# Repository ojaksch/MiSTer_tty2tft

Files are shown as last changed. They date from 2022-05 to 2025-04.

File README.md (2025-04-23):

# This project is now archived and unmaintained

---

*A display add-on for the **[MiSTer FPGA]***

<br>


<div align = right>
<div align = center>

This project is the big brother of Venice's famous [tty2oled](https://github.com/venice1200/MiSTer_tty2oled/), <br>
based on an ESP32 in Arduino MEGA format and an <br>
appropriate 8-bit-bus **TFT** display as a shield. <br>
This setup plays JPG pictures and MJPEG videos <br>
from SD card, optional downloading via WiFi.

Head over to the [documentation folder how to set it up.](https://github.com/ojaksch/MiSTer_tty2tft/tree/main/doc)
</div>
</div>

---

### License

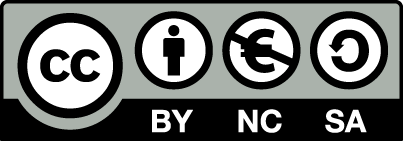
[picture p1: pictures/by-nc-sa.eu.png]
CC BY-NC-SA 4.0
  
[Attribution-NonCommercial-ShareAlike 4.0 International (CC BY-NC-SA 4.0)](https://creativecommons.org/licenses/by-nc-sa/4.0/)

<!----------------------------------------------------------------------------->

[MiSTer FPGA]: https://github.com/MiSTer-devel

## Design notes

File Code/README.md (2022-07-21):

### Used libraries:

- [JPEGDEC](https://github.com/bitbank2/JPEGDEC/)
- [GFX_Library_for_Arduino](https://github.com/moononournation/Arduino_GFX)
- [ESP32Time](https://github.com/fbiego/ESP32Time)
- [CronAlarms](https://github.com/Martin-Laclaustra/CronAlarms)
- [U8g2](https://github.com/olikraus/u8g2)
- [ftpsrv](https://github.com/schreibfaul1/ESP32FTPServer)
- [JpegFunc.h and MjpegClass.h (modified by me)](https://github.com/moononournation/RGB565_video)

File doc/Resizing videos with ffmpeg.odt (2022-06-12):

# Resizing videos with ffmpeg (https://superuser.com/questions/547296/resizing-videos-with-ffmpeg-avconv-to-fit-into-static-sized-player)

(Source: https://superuser.com/questions/547296/resizing-videos-with-ffmpeg-avconv-to-fit-into-static-sized-player/1136305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)

A simple method is to use the force_original_aspect_ratio option in the scale filter (https://ffmpeg.org/ffmpeg-filters.html#scale).

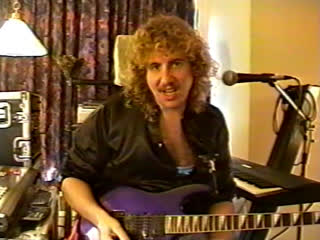
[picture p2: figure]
original image

(https://i.stack.imgur.com/vjgYm.jpg)
Original image. Represents a 640x480, 4:3 aspect ratio video.

In these examples the original image will be scaled to fit into a 1280x720, 16:9 aspect ratio output while preserving the original aspect ratio. To do this you can either:

- Add black bars (or any other color) with pad filter (https://ffmpeg.org/ffmpeg-filters.html#pad) to pillarbox (https://en.wikipedia.org/wiki/Pillarbox) or letterbox (https://en.wikipedia.org/wiki/Letterboxing_(filming)) the image to fit properly, or
- Use the crop filter (https://ffmpeg.org/ffmpeg-filters.html#crop) to cut off the excess

# Pillarbox or letterbox to fit

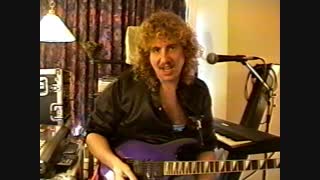
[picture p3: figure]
pillarboxed image

(https://i.stack.imgur.com/wlTki.jpg)
Pillarboxed image. Fitting a 640x480 (4:3) input into a 1280x720 (16:9) output.

ffmpeg -i input -vf "scale=1280:720:force_original_aspect_ratio=decrease,pad=1280:720:-1:-1:color=black" output

- This will upscale the image. If you want to avoid upscaling see the example below.
- Letterboxing will occur instead of pillarboxing if the input aspect ratio is wider than the output aspect ratio. For example, an input with a 2.35:1 aspect ratio fit into a 16:9 output will result in letterboxing.

## Same as above but without upscaling

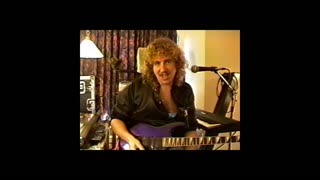
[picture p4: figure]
no upscaling

(https://i.stack.imgur.com/WON8H.jpg)
640x480 (4:3) input into 1280x720 (16:9) output without upscaling.

ffmpeg -i input -vf "scale='min(1280,iw)':min'(720,ih)':force_original_aspect_ratio=decrease,pad=1280:720:-1:-1:color=black" output

# Crop to fit

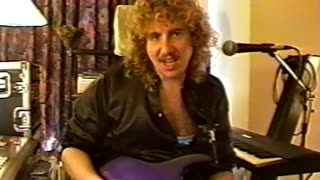
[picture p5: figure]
enter image description here

(https://i.stack.imgur.com/FW2U2.jpg)
Cropped image. 4:3 input aspect ratio, 16:9 output aspect ratio.

Using the crop filter (https://ffmpeg.org/ffmpeg-filters.html#crop) to cut off the excess:

ffmpeg -i input -vf "scale=1280:720:force_original_aspect_ratio=increase,crop=1280:720" output

## Using input images that each vary in size

If you are inputting a series of images, and the images vary in size, add the eval=frame option in the scale filter (https://ffmpeg.org/ffmpeg-filters.html#scale), such as:

ffmpeg -i input -vf "scale=1280:720:force_original_aspect_ratio=decrease:eval=frame,pad=1280:720:-1:-1:color=black" output

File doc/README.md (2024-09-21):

Ready to rumble?

Table of Contents  
[Hardware](#hardware)  
[Software](#software)  
[Media](#media)  
[MJPEG](#mjpeg)  
[The INI files](#the-ini-files)  
[The screensaver](#the-screensaver)  
[Touch function](#touch-function)  
[Swiping](#touch-swipe)  
[Commands](#commands)  
[Color definitions](#color-definitions-used-by-the-display-driver)  
[Initial Animation](initial_animation)  
[Bugs and things to do](#bugs-and-things-still-to-do)  
[Compiling](#compiling)  
[License](#license)  
[Licensees](#licensees)  

---

# Hardware

You need an [ESP32 D1 R32 and an ILI9341 (320x200) 8-bit bus display](https://github.com/ojaksch/MiSTer_tty2tft/blob/main/pictures/d1r32-ili9341.jpg). 
Other 8-bit bus displays should also work (according to librarys documentation). Alternatively you can use the [Adafruit 2.8 SPI based shields](https://www.adafruit.com/product/1947).

- 2024-09: ILI9341-CYD ("Cheap Yellow Display")
- 2022-09: ILI9341 (SPI) (320x240) succesfully tested by Ahmadexp
- 2022-06: ILI9488 (parallel) (480x320) succesfully tested by myself
- 2022-06: ILI9486 (parallel) (480x320) succesfully tested by Salamantecas
- 2022-06: HX8347D (parallel) (320x200) succesfully tested, many many thanks to Salamantecas!  

The ESP with the **parallel** TFT shield needs a [small modifictaion consisting of three cables](https://github.com/ojaksch/MiSTer_tty2tft/blob/main/pictures/d1r32-mod.jpg).
([Source](https://github.com/Bodmer/TFT_eSPI#8-bit-parallel-support)) Not necessary for the SPI shields. 

In order to get the [Adafruit 2.8 SPI based shields](https://www.adafruit.com/product/1947) work on the Wemos D1 R32, it is necessary to [solder the jumper points (D13/12/D13)](https://github.com/ojaksch/MiSTer_tty2tft/blob/main/pictures/ADA28SPI-mod_photo.jpg) on the back of the TFT shield. This is mainly because the Wemos D1 R32 lacks the 6-pin SPI connector.

**Notices:**
- It turned out that a 480x320 display looks great with pictures, but is somewhat too "slow" to play MJPEG videos really fluently. This is stated by the facts 
that MJPEG isn't a videostream...it's a series of single jpg's in one file that are played one after the other and are always shown at 25fps. Keep in mind that a 
480x320 display has a 2.5x resolution of a 320x200 one, so it also has to transfer 2.5 times of data - all this through very limited SD access times.
As a result, my personal recommendation is a 320x200 for pictures **and** videos - or a 480x320 for pictures (and videos if a bit stuttering is acceptable).

- Keep in mind that the ESP32 is using WiFi@2.4 GHz only (if enabled).

That's all!

---

# Software

Follow the instructions below. Don't continue with the next step if something won't run, is showing errors or doing something unexpected/weired.
Call for help first.

- Copy the **content** of *SD_card_content* to a reliable FAT32 formatted SD card <32GB. While beeing there you can fill up the subdirectorys with your own content.
The file **wifi.txt** file contains some important settings only needed if you want to use WiFi, otherwise leave it as it is. When editing, use an editor capable of Linux linebreaks, like notepad++ (Windows).:
  - 1st line: WiFi SSID
  - 2nd line: WiFi Password
  - 3rd line: URL of a picture server for online picture access (set to 127.0.0.1 = disabled)
  - 4th line: WiFi timeout
  - 5th line: WiFi country code
  - 6th line: Opening screen (ORG for my version, OWN for *your* design, OWN0 for *your* design w/o any text overlay
  - 7th line: Display orientation (1 is normal, 3 rotated by 180°)
  - 8th line: Divisor for screen's X-resolution/axis to swipe
  - 9th line: Divisor for screen's Y-resolution/axis to swipe

- Open a ssh-shell to your MiSTer or open a console at MiSTer and logon.

- We will do a quick first test to see that everythins is working / to ensure ESP32 and display are working together. Type in the following line:
for ILI9341: `wget https://raw.githubusercontent.com/ojaksch/tty2tft/main/installer.sh -O - | bash -s -- TEST-ILI9341`  
for ILI9486: `wget https://raw.githubusercontent.com/ojaksch/tty2tft/main/installer.sh -O - | bash -s -- TEST-ILI9486`  
for ILI9488: `wget https://raw.githubusercontent.com/ojaksch/tty2tft/main/installer.sh -O - | bash -s -- TEST-ILI9488`  
for ILI9341SPI: `wget https://raw.githubusercontent.com/ojaksch/tty2tft/main/installer.sh -O - | bash -s -- TEST-ILI9341SPI`  
This will flash a simple and looping graphics demo.   
If you see a message while flashing like
> WARNING: Failed to communicate with the flash chip...

then the ESP doesn't reset quick enough. Just rerun the line from above. 
If flash happened successfuly and demo works, just continue - otherwise stop here, check your hardware/cabling and call for help then.

- Type in  
`wget https://raw.githubusercontent.com/ojaksch/tty2tft/main/installer.sh -O - | bash -s -- FORCE DISPLAYTYPE`  
**DISPLAYTYPE** is the type of your display, one of HX8347D, ILI9341, ILI9486, ILI9488, ILI9341CYD or ILI9341SPI so, for example, your line should read  
`wget https://raw.githubusercontent.com/ojaksch/tty2tft/main/installer.sh -O - | bash -s -- FORCE ILI9341`  
when flashing for a display ILI9341. This will download and flash the ESP firmware. You should see a [welcome screen](https://github.com/ojaksch/MiSTer_tty2tft/blob/main/pictures/000-arcade.jpg) after the reboot of the ESP.  

- Type in  
`wget https://raw.githubusercontent.com/ojaksch/tty2tft/main/update_tty2tft.sh -O - | bash`  
which downloads and setup the software (init and daemon).

Voila, tty2tft is alive :)

---

# Media

JPG pictures must be 320x240 (ILI9341, HX8347D) or 480x320 (ILI9486) pixels in size and should be saved as non-progressive with around 60 percent in compression to achieve 
a good compromise between quality and filesize (=loading time). A filesize around 20kb is fine, the 
smaller, the better, but a filesize around 35kb is ok, too. That's all.

Same goes for the MJPEG videos. Example scripts will follow.

When a core is setting it's MAME setname, tty2tft is working as follows:  
At first tty2tft is looking for a file of the same (set-) name. If one is found tty2tft looks if there's 
also a video of that name and plays the video first (if activated), then the picture as a "photo frame". 
When a file is found tty2tft also looks if there are alternative names, like "qbert_alt1" (up to _alt5) and 
dices out which to play/show.
A video is played only if a) this function is activated and b) there's also a picture of that name.

If a file can't be found tty2tft tries to shorten the filename, in hope that a file in a shorter form can be found then. 
There *are* cores/pictures for the same game but with a different name and ROM, for example *jackal*, *jackalj* and *jackalr*. 
Another example: The is a hypothetical core/game named qbertfixed without a picture for *that* name and tty2tft goes on to shorten the 
name to qbertfixe, then qbertfix, then qbertfi, then qbertf, then qbert and voila! there it is. Got it?

You can access your device by FTP using a FTP program like FileZilla (recommended!) to organise your SD's content. Username and passwort is "esp32" (without quotes).
Limit the "parallel connections" to "1" for this connection.

After displaying core's image sounds can be played through MiSTer by placing a MP3 into /media/fat/tty2tft/sound/  
The MP3 must have the same name as the image. No limitation in length or bitrate, but I recommend short ones with a bitrate of 128 or 192.

---

# MJPEG

## How to create a MJPEG?

Simple. In principle. Really.  
Use a linear video editor like [Avidemux](http://avidemux.sourceforge.net), get your favorite video and cut it down to the needed length.
While beeing there you could add effects etc.

Get and install the famous [ffmpeg](https://ffmpeg.org/) package.
I have found and used the following two tutorials to get an one-liner of code, which is doing all tasks in one go (fade-in at start, rescale, fade-out at end, encode).

[Add Fade In and Fade Out Effects With ffmpeg](https://dev.to/dak425/add-fade-in-and-fade-out-effects-with-ffmpeg-2bj7)

[Resizing videos with ffmpeg](https://superuser.com/questions/547296/resizing-videos-with-ffmpeg-avconv-to-fit-into-static-sized-player/1136305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)

- Pillarbox or letterbox to fit  
```
ffmpeg -y -t 00:10 -i "INPUT_FILE" -an -pix_fmt yuvj420p -vf "fps=13,tpad=stop_duration=1:color=black,fade=t=out:st=9:d=1,scale=320:240:flags=lanczos:force_original_aspect_ratio=decrease,pad=320:240:-1:-1:color=black" -q:v 9 "OUTPUT_FILE.mjpeg"
```

- Same as above but without upscaling  
```
ffmpeg -y -t 00:10 -i "INPUT_FILE" -an -pix_fmt yuvj420p -vf "fps=13,tpad=stop_duration=1:color=black,fade=t=out:st=9:d=1,scale='min(320,iw)':min'(240,ih)':flags=lanczos:force_original_aspect_ratio=decrease,pad=320:240:-1:-1:color=black" -q:v 9 "OUTPUT_FILE.mjpeg"
```

Parameters used here (also see [ffmpeg's documentation page](https://ffmpeg.org/ffmpeg-all.html):

- -t *duration* (limit the duration of data read from the input file.)
- -i *INPUT_FILE* (the source video)
- -an (drop audio)
- -pix_fmt *format* (pixel format)
- -vf *filtergraph* (filtergraph specified by filtergraph and use it to filter the stream)
  - fps=*fps* (frames per second)
  - tpad=*mode* (Temporarily pad video frames - Here: *duration* of the stop delay (*1*), *color* black)
  - fade=*fade effect* (Here: *t*ype fade out, *st*art after 9 seconds, *d*uration 1 second )
  - scale*scale options* (Here: *scale* to 320x240 with *flags* using the *lanczos* rescaling algorithm, *force_original_aspect_ratio=decrease* (decreasing output video width or height if necessary to keep the original aspect ratio) and *pad*ding to WIDTHxHEIGHT2XxY and *color* black
- -q *stream_specifier* *quality* (fixed quality scale (VBR))
- OUTPUT_FILE

---

# The INI files

There are two INI files: **tty2tft-system.ini** and **tty2tft-user.ini** which are read and evaluated by 
the daemon in that order. tty2tft-user.ini is overwriting values done by tty2tft-system.ini  
tty2tft-system.ini contains the system wide variables and definitions. Do not edit this file as it will be overwritten when doing an update!  
For your own favorite variables please use tty2tft-user.ini and take over and edit the needed line 
from tty2tft-system.ini. All useful variables are commented - see "# Userdata" in tty2tft-system.ini

---
# The screensaver

This is a simple screensaver which displays a clock, followed by the MiSTer logo and core's picture (in random order).  
The clock is extendable: If you have another set of nice digits, resize them to the same size as the existing ones and 
save them to your SD in /jpg/displaysize/#/000-clockclockset-0.jpg and so on. For exmaple, if you are creating the 
fourth clock set for your ILI9341, the path would be /jpg/320x240/#/000-clock4-0.jpg for the digit 0. Set SCREENSAVER_TYPE 
to 4 in your tty2tft-user.ini and you're set. Got it?

The time _when_ it is activated and changes is set by parameters shown below.
We are using  `cron` for that which might be misleading (for SCREENSAVER_START) the first time as
this works works a little differently you might think. The timer doesn not start exactly after
the defined "after X minutes" set, but means "start after X minutes beginning from xx:00 o'clock.
For example: "after 2 Minutes" is set, it will start every 2 minutes, i.e. 08:02, 08:04, 08:06 and so on.
Another example: "after 13 Minutes" is set, it will start every 13 minutes, i.e. 08:13, 08:26, 08:39 ...  
The clock/image shown will change after x seconds set with SCREENSAVER_IVAL
```
SCREENSAVER_START="2"           # Start screensaver after x minutes (1-59)
SCREENSAVER_IVAL="10"           # Screensaver Interval (1-59) seconds
```

---

# Touch function

Touch function for the Adafruit 2.8 SPI (see [Hardware](#hardware)) is working. 
Button 7 is predefined and hard coded for SysInfo. All other buttons can be defined by adding/editing 
them to your **tty2tft-user.ini** (see **tty2tft-system.ini** for examples).  

One useful example could be a volume control (thanks to user warham for the inspiration):
```
TOUCHBUTTON1="/media/fat/Scripts/mbc raw_seq :72"
TOUCHBUTTON2="/media/fat/Scripts/mbc raw_seq :71"
TOUCHBUTTON3="/media/fat/Scripts/mbc raw_seq :73"
```
Keep in mind that these are **Hexadecimal** values!  
Button #1 would be then "Volume Down", button #2 "Mute/Unmute", button #3 "Volume Up". **Decimal** keycodes are taken from [this page](https://github.com/torvalds/linux/blob/master/include/uapi/linux/input-event-codes.h).  
There are [templates available in 320x240/480x320](https://github.com/ojaksch/MiSTer_tty2tft/tree/main/pictures) for 
creating your own "Touch Menu" which can used together with [GIMP](https://www.gimp.org/)

---

# Swiping

We are having three touch screens with 27 buttons. To enter the first touch screen just touch your screen when a picture is displayed. 
To navigate between the three screens swipe to the left or right on the X axis of the screen. Swipe to the left to go back one screen, 
swipe to the right to enter the next screen. To exit the touch screen swipe to the top or bottom.

The next picture shows the (default) route how far to swipe. The default is a third of display's X width and 1.3 of display's Y height. 
Diagonal swiping is supported, but a swipe on Y is preferred over X.  
These settings can be defined -  see [Software](#software) and there "Divisor for screen"...

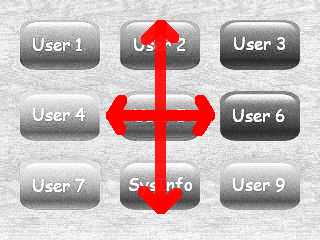
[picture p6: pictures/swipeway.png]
How far to swipe


---

# Commands

If you tend to extend/change/rewrite tty2tft's Daemon (the program which is driving tty2tft), you have a set of commands you can use.

| Commands | Meaning |
| --- |--- |
| CMDCLS | Black out screen |
| CMDCRED | Fill screen red (just for testing) |
| CMDDON | Turn on screen (ILI9341 only) |
| CMDDOFF | Turn off screen (ILI9341 only) |
| CMDDINVON | Invert screen on (ILI9341 only) |
| CMDDINVOFF | Invert screen off (ILI9341 only) |
| CMDRESET | Restart ESP |
| CMDSNAM | Show picture's name |
| CMDOTAUPDATE,PARAM | Start OTA update for display PARAM
| CMDROT,PARAM | Rotate screen (0=none/Portrait, 1=90°/Landscape, 2=180°, 3=270°) |
| CMDDUPD | Refresh screen |
| CMDDELETE | Delete actual picture/video from SD |
| CMDUPLOAD,URL | Upload file from <URL> |
| CMDCOR,MENU | Shows MiSTer Menu |
| CMDCOR,CORENAME | Shows picture/video from SD (filename) |
| CMDSETTIME,TSTAMP | Set time and date (timestamp) |
| CMDVIDEOPLAY,PARAM | Play videos or not (yes/no/may) |
| CMDSAVER,PARAM,PARAM | Screensaver after x mins. (1-59), change after y secs, (1-59) |
| CMDSAVEROPTS,PARAM,PARAM,PARAM  | Screensaver options yes/no (yes=12h, no=24h), (Text screensaver), (Graphical screensaver) |
| CMDHWINF | Send hardware info, BuildVersion and MAC address |
| CMDTXT,PARAM,PARAM,PARAM,PARAM,PARAM | Draw text with font type, text color, background color, x pos, y pos, text

If a picture/video can't be found on SD and WiFi isn't available, show a "...not found..." picture.
But is WiFi available load a **picture** (but not a video) from archive.org and save it on SD.
An upload with CMDUPLOAD saves the picture/video on SD.

### Color definitions used by the display driver:

| Color | Hex | Dec | RGB |
| ---|---|---:|---: |
| BLACK | 0x0000 | 0 | 0, 0, 0 |
| NAVY | 0x000F | 15 | 0, 0, 123 |
| DARKGREEN | 0x03E0 | 992 | 0, 125, 0 |
| DARKCYAN | 0x03EF |  1007 | 0, 125, 123 |
| MAROON | 0x7800 | 30720 | 123, 0, 0 |
| PURPLE | 0x780F | 30735 | 123, 0, 123 |
| OLIVE | 0x7BE0 | 30735 | 123, 125, 0 |
| LIGHTGREY | 0xC618 | 50712 | 198, 195, 198 |
| DARKGREY | 0x7BEF | 31727 | 123, 125, 123 |
| BLUE | 0x001F | 31 | 0, 0, 255 |
| GREEN | 0x07E0 |  2016 | 0, 255, 0 |
| CYAN | 0x07FF |  2047 | 0, 255, 255 |
| RED | 0xF800 | 63488 | 255, 0, 0 |
| MAGENTA | 0xF81F | 63519 | 255, 0, 255 |
| YELLOW | 0xFFE0 | 65504 | 255, 255, 0 |
| WHITE | 0xFFFF | 65535 | 255, 255, 255 |
| ORANGE | 0xFD20 | 64800 | 255, 165, 0 |
| GREENYELLOW | 0xAFE5 | 45029 | 173, 255,  41 |
| PINK | 0xFC18 | 64536 | 255, 130, 198 |

---

# Initial Animation

When tty2tft has finished booting, it is showing my version of an animation plus some text, IP address and version. 
If you want to use your own animation, just follow the hints in the [documentation](https://github.com/ojaksch/MiSTer_tty2tft/blob/main/doc/README.md#mjpeg]documentation), 
save your MPJEG as "000-arcade.mjpeg" to SD overwriting my original one and change the 6th line of wifi.txt from ORG 
to OWN, which disables additional text output over your video after playing. However, version number and a single "T" ("Touch Support available") are still displayed.

---

# Bugs and things still to do

- Check the correct rotation settings

- ~~image resize option for screensaver
https://misterfpga.org/viewtopic.php?p=53857#p53857~~

- Picture of a **game** (not core)
> I think simple matching based off rom filename would be the easiest. It would be up to the
> individual to make sure his/her media is named appropriately. Most of my artwork comes from
> Emumovies.com and the download utility for that site actually looks at the roms in your
> collection and renames the artwork accordingly. The developer of the frontend for my arcade
> machine (GameEx) designed the utility so that he could make sure his program would be able
> to find all the artwork when a game was launched.

- ~~Touch support~~ [Not yet possible for parallel displays](https://github.com/ImpulseAdventure/GUIslice/issues/130)

- [Unreliable WiFi connection](https://github.com/espressif/arduino-esp32/issues/1675)

---

# Compiling

I'm a fan of a command line and using [makeEspArduino](https://github.com/plerup/makeEspArduino) for compiling this Sketch. If you 
are using the Arduino IDE, please select the "ESP32 Dev Module" and "Minimal SPIFFS" for the Partition Scheme. That's all.

---

# License

CC BY-NC-SA 4.0  
[Attribution-NonCommercial-ShareAlike 4.0 International (CC BY-NC-SA 4.0)](https://creativecommons.org/licenses/by-nc-sa/4.0/)

---

# Licensees

Official Licensees to whom I'm very grateful:
- OnCor/MiSTer Consoles  
https://misterfpga.org/search.php?author_id=659&sr=posts  
https://misterfpga.org/search.php?author_id=6780&sr=posts

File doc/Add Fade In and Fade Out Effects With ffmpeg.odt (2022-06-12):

# Add Fade In and Fade Out Effects With ffmpeg

(Source: https://dev.to/dak425/add-fade-in-and-fade-out-effects-with-ffmpeg-2bj7)

I figured out that you don't need to use a full fledge video editor to apply some basic transition effects to video and audio.

Using ffmpeg, you can apply basic fade in and fade out to video using the fade filter. For audio, the afade filter can be used to achieve a similar effect.

ffmpeg -i video.mp4 -vf "fade=t=in:st=0:d=3" -c:a copy out.mp4

This will start the video with a black screen and fade in to full view over 3 seconds.

ffmpeg -i video.mp4 -vf "fade=t=out:st=10:d=5" -c:a copy out.mp4

This will make the video start fading to black over 5 seconds at the 10 second mark.

ffmpeg -i music.mp3 -af "afade=t=in:st=0:d=5" out.mp3

The audio file will start at a low volume and fade in to full over 5 seconds.

ffmpeg -i music.mp3 -af "afade=t=out:st=5:d=5" out.mp3

The audio file will start fading to zero volume over 5 seconds starting at the 5 second mark.

ffmpeg -i video.mp4 -vf "fade=t=in:st=0:d=10,fade=t=out:st=10:d=5" -c:a copy out.mp4

You can apply both fade in and out effects at the same time, to avoid having to re-encode twice.

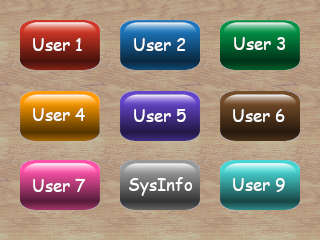
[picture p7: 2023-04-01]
pictures/320x240/#/000-touchscreen1.jpg

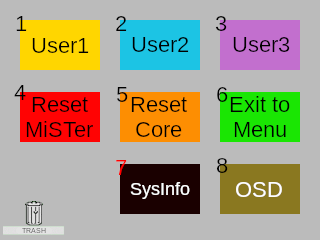
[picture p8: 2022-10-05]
pictures/touch-assignment.png

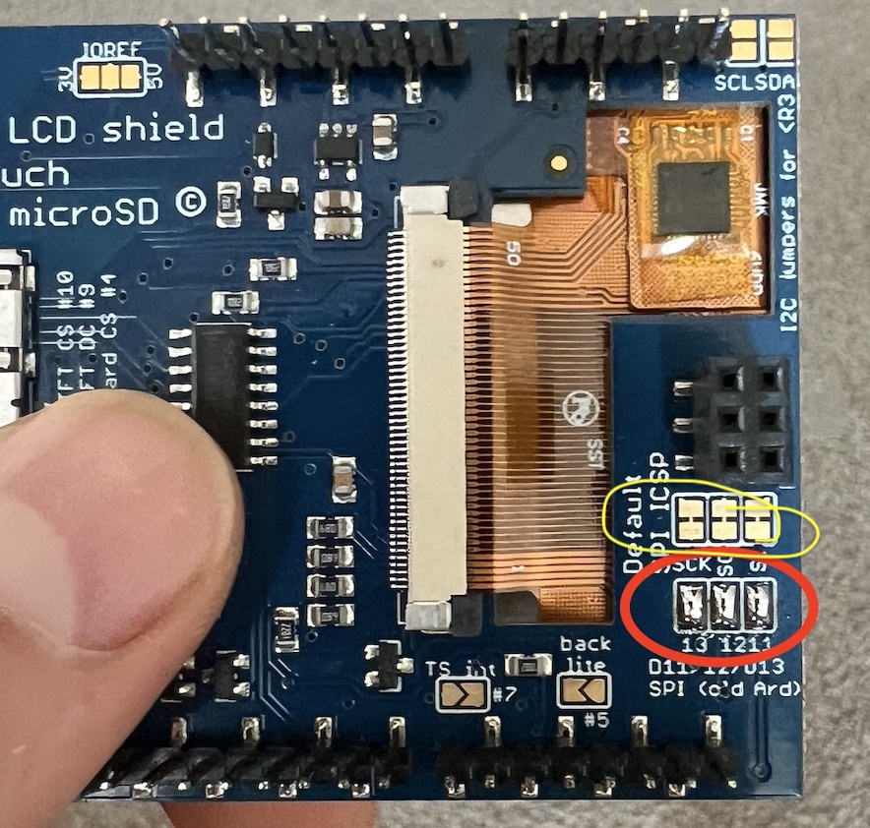
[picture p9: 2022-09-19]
pictures/ADA28SPI-mod_photo.jpg

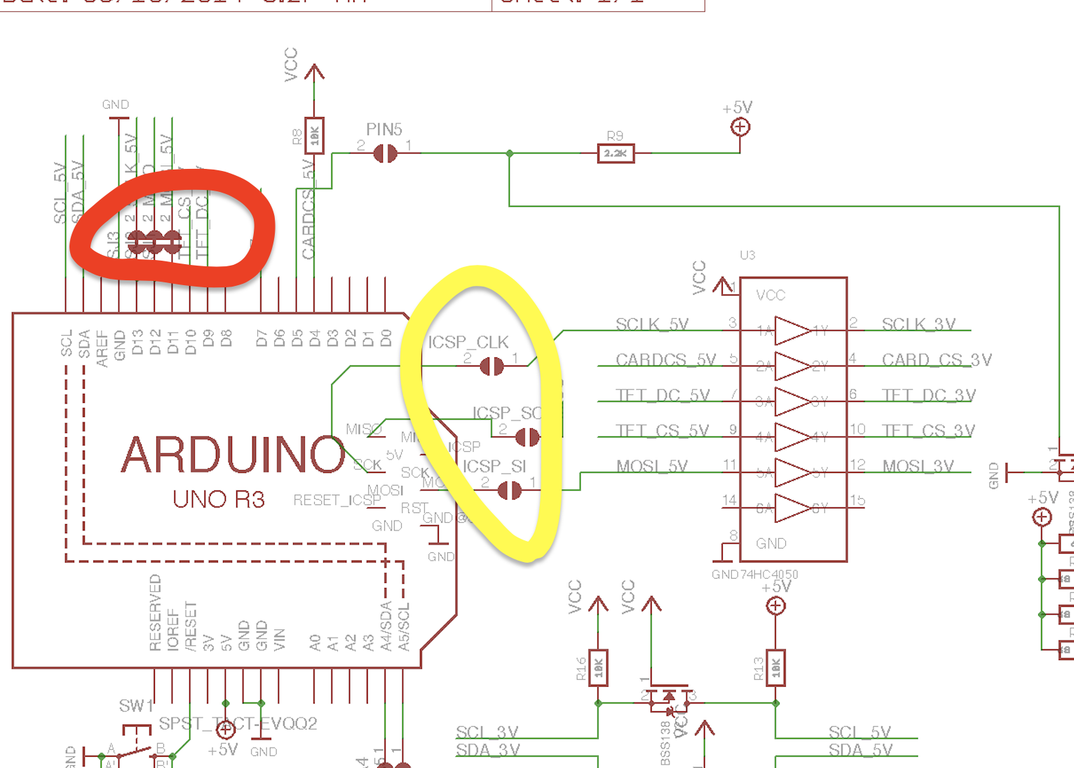
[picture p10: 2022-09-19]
pictures/ADA28SPI-mod_data.jpg

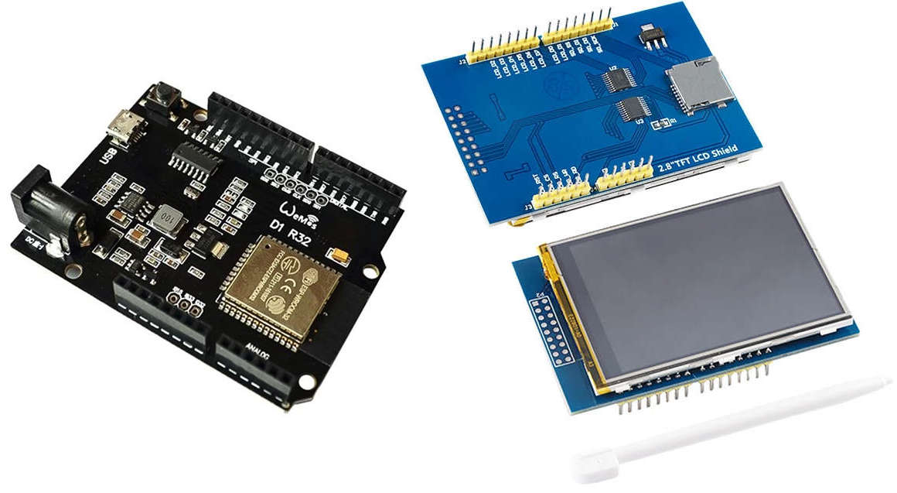
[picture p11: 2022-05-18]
pictures/d1r32-ili9341.jpg

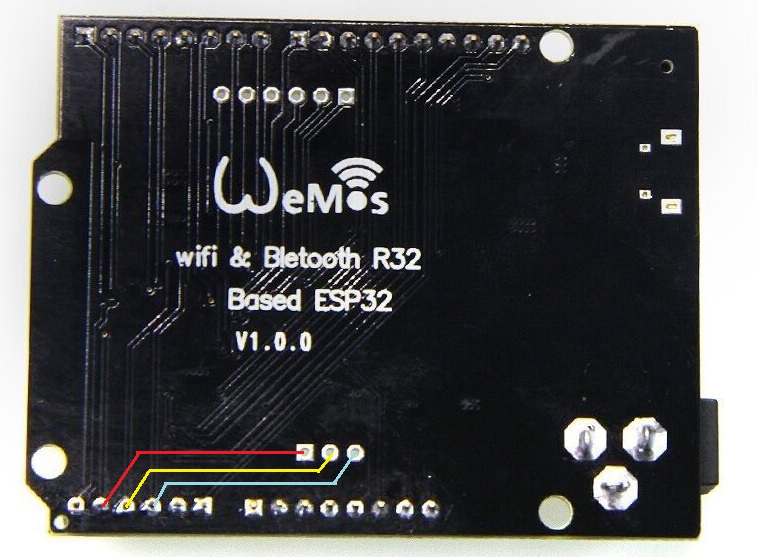
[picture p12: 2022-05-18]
pictures/d1r32-mod.jpg

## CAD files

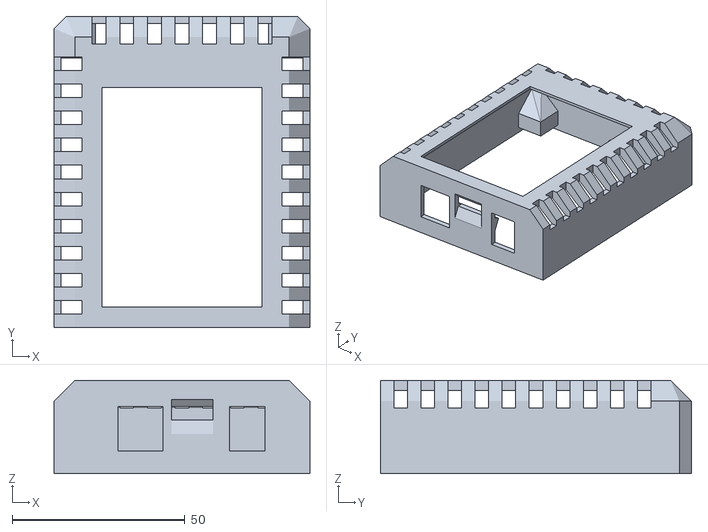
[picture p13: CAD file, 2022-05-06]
cases/sdrive-max-case-v3.1.stl
74.0 x 90.0 x 27.0

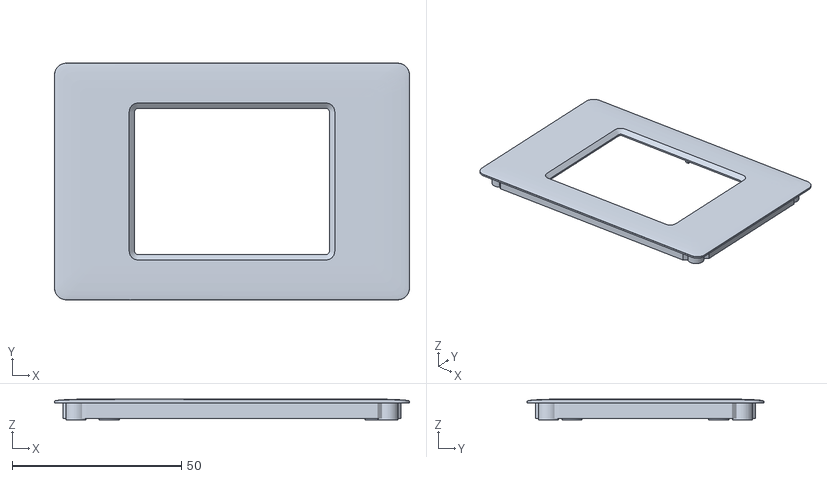
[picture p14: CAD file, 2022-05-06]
cases/2_8_stencil_display.stl
105.0 x 70.0 x 6.15

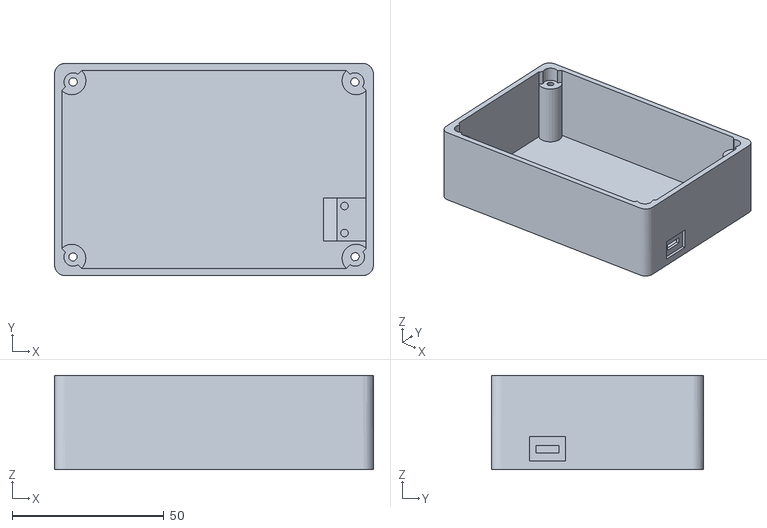
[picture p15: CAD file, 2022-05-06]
cases/2_8_case.stl
105.0 x 69.9 x 31.0

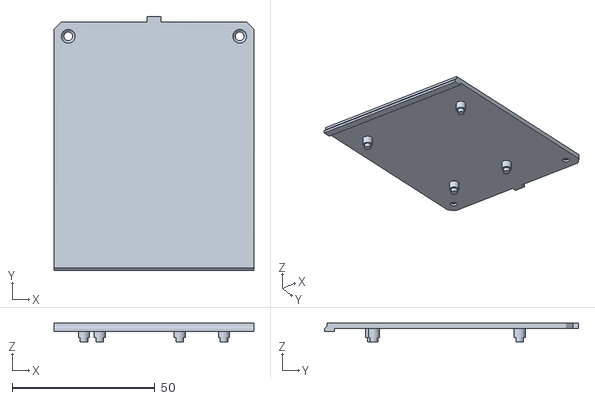
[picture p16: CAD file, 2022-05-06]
cases/sdrive-max-bottom-v3.1.stl
70.0 x 89.0 x 6.63

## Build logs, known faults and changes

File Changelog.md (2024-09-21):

- 230421 - Added display ILI9341-CYD ("Cheap Yellow Display")
- 220617 - Internal changes to the jpeg routine(s), which saved some kb; added dirletter for fetchfile; dirletter to uppercase
- 220616 - Complete overhauled screensaver
- 220615 - Show MENU.jpg (if available) instead of Sorgelig's cat
- 220614 - Display driver for ILI9486 fixed
- 220608 - Change CMDHWINF to a more unique name
- 220607 - Autocalculate positions of media depending on displays dimension
- 220606 - Autodefine display's width/height by used displaytype
- 220605 - Enable FTP only if WiFi is enabled too
- 220604 - Include a FTP server, change SD's directory structure, variables cleanups
- 220521 - CMDTXT with background color
- 220520 - Include u8g2, CMDTXT for text functions
- 220517 - Change filehandle from fs;; to SD
- 220516 - Tests with SDfat
- 220515 - Code cleanups
- 220514 - Changes to WiFi variables and routines
- 220501 - Work on the screensaver function(s)
- n/a    - Include Cron for screensaver function(s)
- 220211 - Include RTC
- 220126 - Improvement and standardization of variables

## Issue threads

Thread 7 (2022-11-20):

Possible on lilygo t display s3?

BulletMag, 2022-11-20:
I have just purchased one of the LilyGO t-display S3 and was wondering if this project would work on it?

ojaksch, 2022-11-20:
Should work and [display driver is available](https://github.com/moononournation/Arduino_GFX/blob/master/src/display/Arduino_ST7789.cpp), but keep in mind that code and pictures are designed for 320x240 and 480x320 - the ST7789 is having 320x170. Imho it (currently) makes no sense to extend the code for unusual display dimensions, so for now you are on your own in forking and changing the code for you own needs. That can certainly change if more users are having a similar display/resolution where I'd change the code to be more modular.

ojaksch, 2025-04-23:
Never got an answer. Closing.

Closed 2025-04-23.

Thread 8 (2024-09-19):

CYD Support?

Arakon, 2024-09-19:
Hi.

Are there any plans or any methods to get the CYD to work (Cheap Yellow Display)?
It's a very cheap display that consists of a screen in 2.8-4.8" sizes with an ESP32 onboard.
Examples: https://www.aliexpress.com/item/1005006110360174.html and https://www.aliexpress.com/item/1005005928255980.html

These would be a very simple way to get a display set up for use with the MiSTer, for far less money than the seperate parts. The 2.8" variant seems to use an ILI9341 driver.

Some more info: https://randomnerdtutorials.com/cheap-yellow-display-esp32-2432s028r/

I had tried flashing the various display test bin files, but to no avail.

ojaksch, 2024-09-22:
After our [conversation at the forum](https://misterfpga.org/viewtopic.php?p=90531&sid=9d1f33949e2d6db4fde105c37bb8e7a2#p90531) this got implemented.
Many thanks for contributing!

Closed 2024-09-22.

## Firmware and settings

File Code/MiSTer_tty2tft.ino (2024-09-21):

// needs the following librarys:
// JPEGDEC			https://github.com/bitbank2/JPEGDEC
// GFX_Library_for_Arduino	https://github.com/moononournation/Arduino_GFX
// ESP32Time			https://github.com/fbiego/ESP32Time
// CronAlarms			https://github.com/Martin-Laclaustra/CronAlarms
// U8g2				https://github.com/olikraus/u8g2
// ftpsrv			https://github.com/schreibfaul1/ESP32FTPServer
// Adafruit_FT6206_Library	https://github.com/adafruit/Adafruit_FT6206_Library	(for ILI9341SPI)
//
// edit JPEGDEC.h and change the values of
// JPEG_FILE_BUF_SIZE and MAX_BUFFERED_PIXELS to 4096
//
//
// Don't forget to set your display type - see line IMPORTANT: CHANGE THIS TO YOUR CORRESPONDING DEVICE below
//
// crc32: https://github.com/bakercp/CRC32
// swipe: https://www.codeproject.com/Articles/5287929/Swipe-Gestures-Using-a-TFT-Display
//	  https://www.hackster.io/rakshith_bk/esp32-touch-slider-217156


// Neuer wifi.txt Parameter: ORG/OWN


//#define XDEBUG													// Uncomment to receive debug messages by serial output
String BuildVersion = "230421";
int DispRotation = 1;													// 0=normal portrait, 1=landscape, 2=portrait 180°, 3=landscape 180°

// IMPORTANT: CHANGE THIS TO YOUR CORRESPONDING DEVICE
#define ILI9341														// Possible values are: HX8347D,ILI9341,ILI9486,ILI9488,ILI9481_18bit,ILI9341SPI

// SD card access
#ifdef ILI9341SPI
  #define SD_CS 17													// used for Adafruit 2.8 SPI based TFT shield
#elif defined(ILI9341SPIAZ)
  #define SD_CS 5													// used for AZ-Delivery 2.8 SPI based TFT shield
#else
  #define SD_CS 5													// used for all other shields
#endif

#include <SD.h>
#include <FS.h>
File filehandle;
/*
#include "SdFat.h"
#define SPI_SPEED SD_SCK_MHZ(25)
int SD_CS_PIN = 5;
SdFat32 SD;
File32 dir;
File32 file;
File32 root;
File32 filehandle;
*/

// WiFi
#include <WiFi.h>
#include <HTTPClient.h>

// Setup display and JPG libs
#include <Wire.h>
#include <U8g2lib.h>
#include <Arduino_GFX_Library.h>											// Hardware-specific library
#ifdef ILI9341SPI
  Arduino_DataBus *bus = new Arduino_ESP32SPI(13 /* DC */, 5 /* CS */, 18 /* SCK */, 23 /* MOSI */, 19 /* MISO */, VSPI /* spi_num */);		// used for Adafruit 2.8 SPI based TFT shield
#elif defined(ILI9341SPIAZ)
  Arduino_DataBus *bus = new Arduino_ESP32SPI( 4 /* DC */, 5 /* CS */, 18 /* SCK */, 23 /* MOSI */, 19 /* MISO */, VSPI /* spi_num */);		// used for AZ-Delivery 2.8 SPI based TFT shield
#elif defined(ILI9341CYD)
  Arduino_DataBus *bus = new Arduino_ESP32SPI( 2 /* DC */, 15 /* CS */, 14 /* SCK */, 13 /* MOSI */, 12 /* MISO */, VSPI /* spi_num */);	// used for CYD
  #define GFX_BL 21	// default backlight pin, you may replace DF_GFX_BL to actual backlight pin
#else
  Arduino_DataBus *bus = new Arduino_ESP32PAR8(15 /* DC */, 33 /* CS */, 4 /* WR */, 2 /* RD */, 12 /* D0 */, 13 /* D1 */, 26 /* D2 */, 25 /* D3 */, 17 /* D4 */, 16 /* D5 */, 27 /* D6 */, 14 /* D7 */);
#endif

#ifdef ILI9341
  Arduino_GFX *gfx = new Arduino_ILI9341(bus, 32 /* RST */, DispRotation /* rotation */, false /* IPS */);
  const uint8_t *DEFAULT_FONT = u8g2_font_6x10_mf;									// Default font for 320x240 (HX8347x/ILI9341)
  #include "touch.h"													// TOUCH for AZ-Delivery 2.8 SPI based TFT shield
#elif defined(ILI9481_18bit)
  Arduino_GFX *gfx = new Arduino_ILI9481_18bit(bus, 32 /* RST */, DispRotation /* rotation */, false /* IPS */);
  const uint8_t *DEFAULT_FONT = u8g2_font_6x10_mf;									// Default font for 320x240 (HX8347x/ILI9341)
  #include "touch.h"													// TOUCH for AZ-Delivery 2.8 SPI based TFT shield
#elif defined(ILI9341SPI)
  Arduino_GFX *gfx = new Arduino_ILI9341(bus, 12 /* RST */, DispRotation /* rotation */, false /* IPS */);		// used for Adafruit 2.8 SPI based TFT shield
  const uint8_t *DEFAULT_FONT = u8g2_font_6x10_mf;									// Default font for 320x240 (HX8347x/ILI9341)
  #include <Adafruit_FT6206.h>												// TOUCH for Adafruit 2.8 SPI based TFT shield
  Adafruit_FT6206 ts = Adafruit_FT6206();
#elif defined(ILI9341SPIAZ)
  Arduino_GFX *gfx = new Arduino_ILI9341(bus, 22 /* RST */, DispRotation /* rotation */, false /* IPS */);		// used for Adafruit 2.8 SPI based TFT shield
  const uint8_t *DEFAULT_FONT = u8g2_font_6x10_mf;									// Default font for 320x240 (HX8347x/ILI9341)
#elif defined(ILI9341CYD)
  Arduino_GFX *gfx = new Arduino_ILI9341(bus, -1 /* RST */, DispRotation /* rotation */, false /* IPS */);		// used for CYD ("Cheap Yellow Display")
  const uint8_t *DEFAULT_FONT = u8g2_font_6x10_mf;									// Default font for 320x240 (HX8347x/ILI9341)
  #include "touch.h"													// TOUCH for AZ-Delivery 2.8 SPI based TFT shield
#elif defined(ILI9486)
  Arduino_GFX *gfx = new Arduino_ILI9486(bus, 32 /* RST */, DispRotation /* rotation */, false /* IPS */);
  const uint8_t *DEFAULT_FONT = u8g2_font_9x15_mf;									// Default font for 480x320 (ILI9486/ILI9488)
  #include "touch.h"													// TOUCH for AZ-Delivery 2.8 SPI based TFT shield
#elif defined(ILI9488)
  Arduino_GFX *gfx = new Arduino_ILI9488(bus, 32 /* RST */, DispRotation /* rotation */, false /* IPS */);
  const uint8_t *DEFAULT_FONT = u8g2_font_9x15_mf;									// Default font for 480x320 (ILI9486/ILI9488)
  #include "touch.h"													// TOUCH for AZ-Delivery 2.8 SPI based TFT shield
#elif defined(HX8347C)
  Arduino_GFX *gfx = new Arduino_HX8347C(bus, 32 /* RST */, DispRotation /* rotation */, true /* IPS */);
  const uint8_t *DEFAULT_FONT = u8g2_font_6x10_mf;									// Default font for 320x240 (HX8347x/ILI9341)
  #include "touch.h"													// TOUCH for AZ-Delivery 2.8 SPI based TFT shield
#elif defined(HX8347D)
  Arduino_GFX *gfx = new Arduino_HX8347D(bus, 32 /* RST */, DispRotation /* rotation */, true /* IPS */);
  const uint8_t *DEFAULT_FONT = u8g2_font_6x10_mf;									// Default font for 320x240 (HX8347x/ILI9341)
  #include "touch.h"													// TOUCH for AZ-Delivery 2.8 SPI based TFT shield
#endif

// RTC functions
#include <ESP32Time.h>
ESP32Time rtc;

// cron functions
#include <time.h>
#include "CronAlarms.h"
CronId cronid1;
CronId cronid2;

// jpg and mjpeg routines
#include "JpegFunc.h"
#include "MjpegClass.h"
static MjpegClass mjpeg;

#include "ESP32FtpServer.h"
#define FTP_USERNAME		"esp32"											// user and pw in FTP Client
#define FTP_PASSWORD		"esp32"
FtpServer ftpSrv;

// OTA update
#include <Update.h>

#include "espmake.h"

// ------------ Variables ----------------

int baudrate = 115200;													// 115200, 921600
int menuloadad = 0;
int ScreenSaverSet = false;
String Dummystring = "";
String ScreenSaverAMPM = "no";
String ScreenSaverClock = "yes";
String ScreenSaverText = "no";
String ScreenSaverPict = "yes";
String ScreenSaverMove = "yes";
String ScreenSaverType = "1";
int ScreenSaverDotCol = WHITE;
int randomold =0;
int randomnew =0;
String hour1 = "";
String hour2 = "";
String minute1 = "";
String minute2 = "";
String second1 = "";
String second2 = "";
int filesize = 0;
int DispWidth = 0;
int DispHeight = 0;
int OffsetX = 0;
int OffsetY = 0;
float ExtraOffsetX = 1;
float ExtraOffsetY = 1;
String folderjpg = "";
String foldermjpeg = "";
String dirletter = "";
String newCommand = "";
String prevCommand = "";
String actCorename = "No Core loaded";											// Actual Received Corename
String oldCorename = "";
String corefilename = "";												// Actual Path+actCorename+Fileextension
String picfnam = "";													// Filename with extension
String fileext = "";													// Fileextension
String displaytype ="";
unsigned int stringlength = 0;
String text = "";
String randNumber = "";
String videoplay = "yes";
String wifiMacString = "";
char spinner = 45;
File myOrigFile;
File myDestFile;
char cron1[15];														// Cron timer #1
char cron2[15];														// Cron timer #2
String WSSID = "SSID";
String WPASS = "PW";
String WIFItimeout = "20";
char *WIFICountry[2];
String OwnMenu = "ORG";
int touchcoordX;
int touchcoordY;
String divisorX;
String divisorY;

String URL = "https://127.0.0.1";
bool USE_WIFI = false;

uint8_t *mjpeg_buf;													// <<== For malloc in Setup

// ================ SETUP ==================
void setup(void) {
  Serial.begin(baudrate);												// 115200 for MiSTer ttyUSBx Device UART Chip on ESP32
  Serial.flush();													// Wait for empty Send Buffer
  Serial.setTimeout(500);												// Set max. Serial "Waiting Time", default = 1000ms

  randomSeed(analogRead(34));												// Init Random Generator with empty Port Analog value

  rtc.setTime(1640995200);												// UTC UNIX time (2022-01-01)
  /*
  // Set all chip selects high to avoid bus contention during initialisation of each peripheral
  digitalWrite(22, HIGH);												// Touch controller chip select (if used)
  digitalWrite(15, HIGH);												// TFT screen chip select
  digitalWrite( 5, HIGH);												// SD card chips select, must use GPIO 5 (ESP32 SS)
  */

  // Initialise the TFT
  gfx->begin();
  gfx->begin(80000000);		// 80 MHz
  #ifdef GFX_BL
    pinMode(GFX_BL, OUTPUT);												// set backlight to pin X, if defined
    digitalWrite(GFX_BL, HIGH);
  #endif
  #ifdef ILI9341CYD
    bus->sendCommand(ILI9341_INVON);											// CYD needs inverted colors
  #endif
  gfx->fillScreen(BLACK);
  gfx->setUTF8Print(true);												// enable UTF8 support for the Arduino print() function
  DispWidth = gfx->width();
  DispHeight = gfx->height();
  folderjpg = "/jpg/" + String(DispWidth) + "x" + String(DispHeight) + "/";
  foldermjpeg = "/mjpeg/" + String(DispWidth) + "x" + String(DispHeight) + "/";
  #define MJPEG_BUFFER_SIZE (gfx->width() * gfx->height() * 2 / 4)							// memory for a single JPEG frame
  //if (DispWidth == 320) playpicture("000-sorgcat", 135, 95 ,0);

  if (DispWidth == 480) {												// Sorgcat begins at 200x130
    OffsetX = 60; // 65
    OffsetY = 34; // 35
    ExtraOffsetX = 1.5;
    ExtraOffsetY = 1.333;
  }

  // Initialise SD card, set SPI to 80 MHz
  if (!SD.begin(SD_CS, SPI, 80000000)) {
  //if (!SD.begin(SD_CS_PIN, SPI_SPEED)) {										// SdFat
    Serial.println(F("SD.begin failed!"));
    writetext("Error while initialising SD. Halting.", 1, 0, 20, DEFAULT_FONT, 0, BLUE, false, "clear");
    while (1) delay(0);
  }

  wifiMacString = WiFi.macAddress();

  // Read WiFi Credentials from SD
  filehandle = SD.open("/wifi.txt", "r");
  if (!filehandle) {
    writetext("Could not open the file wifi.txt", 1, 20, 30, DEFAULT_FONT, 0, YELLOW, false, "");
    while (1) delay(0);
  } else {
    WSSID = filehandle.readStringUntil('\n');
    WPASS = filehandle.readStringUntil('\n');
    URL = filehandle.readStringUntil('\n');

    WIFItimeout = filehandle.readStringUntil('\n');
    if (WIFItimeout.isEmpty()) WIFItimeout = "20";

    String WIFIcountry = filehandle.readStringUntil('\n');
    if (WIFIcountry.isEmpty()) {
      WIFIcountry = "US";
    } else {
      WIFIcountry.toCharArray(*WIFICountry, 2);
    }

    if (WSSID == "SSID" && WPASS == "PW") {
      writetext("No valid WiFi credentials, WiFi disabled.", 1, 20, 30, DEFAULT_FONT, 0, YELLOW, false, "");
      delay(1000);
    } else {
      USE_WIFI = true;													// valid SSID/PW found
    }

    OwnMenu = filehandle.readStringUntil('\n');
    if (OwnMenu != "ORG" && OwnMenu != "OWN" && OwnMenu != "OWN0") OwnMenu = "ORG";

    String rot = filehandle.readStringUntil('\n');
    if (rot.isEmpty()) rot == "1";
    gfx->setRotation(rot.toInt());
    DispRotation = rot.toInt();

    divisorX = filehandle.readStringUntil('\n');
    if (divisorX.isEmpty()) divisorX = "3";
    divisorY = filehandle.readStringUntil('\n');
    if (divisorY.isEmpty()) divisorY = "1.5";
  }
  filehandle.close();

  mjpeg_buf = (uint8_t *) malloc(MJPEG_BUFFER_SIZE);									// Video buffer

  showarcade();														// Initial screen
  if (OwnMenu == "ORG") {
    writetext("- tty2tft -", 0, 127, 85, DEFAULT_FONT, 0, random(0xFFFF), false, "");
    writetext("Welcome!", 0, 138, 98, DEFAULT_FONT, 0, random(0xFFFF), false, "");
  }
  if (OwnMenu == "ORG" || OwnMenu == "OWN") {
    writetext(BuildVersion, 0, 275, 233, DEFAULT_FONT, 3, YELLOW, false, "");
  }

  #ifdef ILI9341SPI
    if (!ts.begin(160)) {												// TOUCH - The bigger the threshold, the more sensible is the touch
      writetext("NT", 0, 10, 233, DEFAULT_FONT, 3, RED, false, "");
    }
    if (OwnMenu == "ORG" || OwnMenu == "OWN") {
      writetext("T", 0, 10, 233, DEFAULT_FONT, 3, RED, false, "");
    }   
  #endif

  if (USE_WIFI) {
    // https://github.com/esp8266/Arduino/blob/master/tools/sdk/include/user_interface.h#L750-L760
    //wifi_country_t WIFIcountry;		// https://github.com/esp8266/Arduino/issues/7083
    WiFi.mode(WIFI_STA);												// Explicit use of STA mode
    //WiFi.setAutoConnect(true);
    WiFi.setAutoReconnect(true);

    for (int i = 1; i <= 4; i++) {
      int startTime = millis();
      WiFi.disconnect();												// Disconnect from AP if it was previously connected
      WiFi.begin(WSSID.c_str(), WPASS.c_str(), WIFI_ALL_CHANNEL_SCAN);
      WiFi.persistent(true);												// Store Wifi configuration in Flash?
      if (OwnMenu == "ORG") writetext("Waiting for WiFi", 0, 105, 125, DEFAULT_FONT, 0, YELLOW, false, "");
      if (i == 2 && OwnMenu == "ORG") writetext("(" + String(i) + "nd try)", 0, 135, 138, DEFAULT_FONT, 0, YELLOW, false, "");
      if (i == 3 && OwnMenu == "ORG") writetext("(" + String(i) + "rd try)", 0, 135, 138, DEFAULT_FONT, 0, YELLOW, false, "");
      while (WiFi.status() != WL_CONNECTED && (millis() - startTime) <= WIFItimeout.toInt() * 1000) {			// Try to connect for 5 seconds
	if (OwnMenu == "ORG") {
	  rotatespinner();
	  rectfill(210, 117, 15, 15, BLACK);
	  writetext(String(spinner), 0, 210, 125, DEFAULT_FONT, 0, YELLOW, false, "");
	}
	#ifdef XDEBUG
	  Serial.print("WiFi status: ");
	  Serial.println(WiFi.status());
	#endif
	delay(250);
      }
      if (WiFi.status() == WL_CONNECTED) break;
    }
    if (OwnMenu == "ORG") rectfill(100, 115, 125, 25, BLACK);								// Clear the row of "Establishing connection"

    if (WiFi.localIP().toString() == "0.0.0.0") {
      USE_WIFI = false;
      if (OwnMenu == "ORG") {
        writetext("Couldn't connect", 0, 115, 117, DEFAULT_FONT, 0, RED, false, "");
        writetext("Continuing w/o WiFi", 0, 105, 127, DEFAULT_FONT, 0, RED, false, "");
      }
    } else {
      if (OwnMenu == "ORG") writetext("IP: " + WiFi.localIP().toString(), 0, 110, 122, DEFAULT_FONT, 0, random(0xFFFF), false, "");
    }

  }
  if (OwnMenu == "ORG") {
    writetext("Waiting for", 0, 128, 153, DEFAULT_FONT, 0, random(0xFFFF), false, "");
    writetext("Menu or Core", 0, 125, 163, DEFAULT_FONT, 0, random(0xFFFF), false, "");
  }
  menuloadad = 1;

  if (USE_WIFI) ftpSrv.begin(SD, FTP_USERNAME, FTP_PASSWORD);								//username, password for ftp.
}
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

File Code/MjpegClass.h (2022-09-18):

/*******************************************************************************
 * JPEGDEC Wrapper Class
 *
 * Dependent libraries:
 * JPEGDEC: https://github.com/bitbank2/JPEGDEC.git
 ******************************************************************************/
#ifndef _MJPEGCLASS_H_
#define _MJPEGCLASS_H_

#define READ_BUFFER_SIZE 4096
#define MAXOUTPUTSIZE (MAX_BUFFERED_PIXELS / 16 / 16)

/* Wio Terminal */
#if defined(ARDUINO_ARCH_SAMD) && defined(SEEED_GROVE_UI_WIRELESS)
#include <Seeed_FS.h>
#elif defined(ESP32) || defined(ESP8266)
#include <FS.h>
#else
#include <SD.h>
#endif

#include <JPEGDEC.h>

class MjpegClass
{
public:
  bool setup(
      Stream *input, uint8_t *mjpeg_buf, JPEG_DRAW_CALLBACK *pfnDraw, bool useBigEndian,
      int x, int y, int widthLimit, int heightLimit)
  {
    _input = input;
    _mjpeg_buf = mjpeg_buf;
    _pfnDraw = pfnDraw;
    _useBigEndian = useBigEndian;
    _x = x;
    _y = y;
    _widthLimit = widthLimit;
    _heightLimit = heightLimit;
    _inputindex = 0;

    if (!_read_buf)
    {
      _read_buf = (uint8_t *)malloc(READ_BUFFER_SIZE);
    }

    return true;
  }

  bool readMjpegBuf()
  {
    if (_inputindex == 0)
    {
      _buf_read = _input->readBytes(_read_buf, READ_BUFFER_SIZE);
      _inputindex += _buf_read;
    }
    _mjpeg_buf_offset = 0;
    int i = 0;
    bool found_FFD8 = false;
    while ((_buf_read > 0) && (!found_FFD8))
    {
      i = 0;
      while ((i < _buf_read) && (!found_FFD8))
      {
        if ((_read_buf[i] == 0xFF) && (_read_buf[i + 1] == 0xD8)) // JPEG header
        {
          // Serial.printf("Found FFD8 at: %d.\n", i);
          found_FFD8 = true;
        }
        ++i;
      }
      if (found_FFD8)
      {
        --i;
      }
      else
      {
        _buf_read = _input->readBytes(_read_buf, READ_BUFFER_SIZE);
      }
    }
    uint8_t *_p = _read_buf + i;
    _buf_read -= i;
    bool found_FFD9 = false;
    if (_buf_read > 0)
    {
      i = 3;
      while ((_buf_read > 0) && (!found_FFD9))
      {
        if ((_mjpeg_buf_offset > 0) && (_mjpeg_buf[_mjpeg_buf_offset - 1] == 0xFF) && (_p[0] == 0xD9)) // JPEG trailer
        {
          // Serial.printf("Found FFD9 at: %d.\n", i);
          found_FFD9 = true;
        }
        else
        {
          while ((i < _buf_read) && (!found_FFD9))
          {
            if ((_p[i] == 0xFF) && (_p[i + 1] == 0xD9)) // JPEG trailer
            {
              found_FFD9 = true;
              ++i;
            }
            ++i;
          }
        }

        // Serial.printf("i: %d\n", i);
        memcpy(_mjpeg_buf + _mjpeg_buf_offset, _p, i);
        _mjpeg_buf_offset += i;
        size_t o = _buf_read - i;
        if (o > 0)
        {
          // Serial.printf("o: %d\n", o);
          memcpy(_read_buf, _p + i, o);
          _buf_read = _input->readBytes(_read_buf + o, READ_BUFFER_SIZE - o);
          _p = _read_buf;
          _inputindex += _buf_read;
          _buf_read += o;
          // Serial.printf("_buf_read: %d\n", _buf_read);
        }
        else
        {
          _buf_read = _input->readBytes(_read_buf, READ_BUFFER_SIZE);
          _p = _read_buf;
          _inputindex += _buf_read;
        }
        i = 0;
      }
      if (found_FFD9)
      {
        return true;
      }
    }

    return false;
  }

  bool drawJpg()
  {
    _remain = _mjpeg_buf_offset;
    _jpeg.openRAM(_mjpeg_buf, _remain, _pfnDraw);
    if (_scale == -1)
    {
      // scale to fit height
      int iMaxMCUs;
      int w = _jpeg.getWidth();
      int h = _jpeg.getHeight();
      float ratio = (float)h / _heightLimit;
      if (ratio <= 1)
      {
        _scale = 0;
        iMaxMCUs = _widthLimit / 16;
      }
      else if (ratio <= 2)
      {
        _scale = JPEG_SCALE_HALF;
        iMaxMCUs = _widthLimit / 8;
        w /= 2;
        h /= 2;
      }
      else if (ratio <= 4)
      {
        _scale = JPEG_SCALE_QUARTER;
        iMaxMCUs = _widthLimit / 4;
        w /= 4;
        h /= 4;
      }
      else
      {
        _scale = JPEG_SCALE_EIGHTH;
        iMaxMCUs = _widthLimit / 2;
        w /= 8;
        h /= 8;
      }
      _jpeg.setMaxOutputSize(iMaxMCUs);
      _x = (w > _widthLimit) ? 0 : ((_widthLimit - w) / 2);
      _y = (_heightLimit - h) / 2;
    }
    if (_useBigEndian)
    {
      _jpeg.setPixelType(RGB565_BIG_ENDIAN);
    }
    _jpeg.decode(_x, _y, _scale);
    _jpeg.close();

    return true;
  }

private:
  Stream *_input;
  uint8_t *_mjpeg_buf;
  JPEG_DRAW_CALLBACK *_pfnDraw;
  bool _useBigEndian;
  int _x;
  int _y;
  int _widthLimit;
  int _heightLimit;

  uint8_t *_read_buf;
  int32_t _mjpeg_buf_offset = 0;

  JPEGDEC _jpeg;
  int _scale = -1;

  int32_t _inputindex = 0;
  int32_t _buf_read;
  int32_t _remain = 0;
};

#endif // _MJPEGCLASS_H_

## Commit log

2022-06-08 Installer: Don't use hardcoded device
2022-06-08 S60: Detect wrong tty* devices
2022-06-08 S60: WIP - Detect wrong tty* devices
2022-07-08 Switchable clock
2022-09-19 add support for Adafruit 2.8 SPI based shields
2022-09-19 Picutres of the mod for Adafruit's 2.8in SPI display
2022-09-20 INO header: A hint to SD_CS for Adafruit 2.8 SPI TFT
2022-09-23 Doc: mention SPI and parallel
2022-09-28 Cleanup in header, fixed HTTP 302
    [MiSTer_tty2tft.ino]
2022-10-05 Fixed Trash Can for 480x320
    [MiSTer_tty2tft.ino]
2022-10-20 Removed double mentioned -three wires-
2022-10-21 Set touch button OSD to -real- F12
